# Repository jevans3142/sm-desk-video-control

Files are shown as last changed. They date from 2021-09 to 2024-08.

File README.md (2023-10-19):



# ADC Theatre - SM Desk Video Switcher

This repository hosts the hardware (in the form of KiCad schematics and PCB layouts) and 
firmware (in the form of C code) of the [ADC Theatre's](https://www.adctheatre.com) Stage 
Manager's Desk Video Switcher. This is a control panel within the SM desk on stage which 
provides remote control of a Blackmagic Design Videohub SDI switcher via Ethernet.

## Features
* Controls four screen outputs on the SM Desk, with six sources (which can differ for each of the screens) routable via 24 buttons on the desk
* Provides a special 'Show Relay' source which is switched between the Main and IR camera both on the SM Desk and around the building
* Is the interface for the Main/IR switch button the SM Desk, and also controls the mains contactor to activate the IR floodlights when in IR camera mode

## Configuration

Although some things such as number of buttons etc are fixed in hardware, some aspects can be customised via a text file 
on a microSD card read at boot. This provides the ADC with the ability to reconfigure for example which sources are availible on the SM desk without having to recompile firmware (as long as the physical buttons are relabeled of course!)

Items which can be configured: 
* Which router inputs are used as sources for each of the destinations 
* For the special 'Show Relay' source, which router inputs are the Main and IR camera 
* Which router outputs are used as 'Show Relay' outputs and should be automatically switched between Main and IR cameras in sync with the SM Desk
* IP address of the router

## Compilation
The microcontroller used is an ESP32 on an Olimex ESP32-PoE-ISO board. After standard installation of the esp-idf FreeRTOS toolchain, currently building on v5.1.1 as a stable version with the configuration included in the src folder (ie. when building do not run the idf.py set-target esp32 command as directed in the esp-idf Getting Started instructions to set up the default build config - just go straight to idf.py build)

## Hardware

There are two types of PCB required. Four 'switch-module' PCBs sit behind the four sets of buttons on the SM desk (four 
destinations with six sources each). One 'main-board' PCB is connected to these panel boards via ribbon cables, and also 
to Ethernet and power.

## Copyright
Copyright (c) 2021-2022 John Evans and contributors.
The ADC SM Desk Video Switcher hardware and firmware is released under Version 3 of the GNU General Public License.
See the LICENSE file for full details.

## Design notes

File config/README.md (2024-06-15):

# ADC Theatre - SM Desk Video Switcher
## Configuration file format

An example configuration file for the SD card is included in this folder.
Any line beginning with // is regarded as a comment. 
The variable names must not be changed otherwise they will not be recognised. The equals sign also must be present. 

### Routing panel sources/destinations
Controls which source is routed to destination for each button and which output way on the router is used for each set of buttons.
Allowed values for sources: 1-40 = sources 1-40 on router, 99 = Show relay main/IR switched 'magic source'
Allowed values for destinations: 1-40 = destinations on router

| Variable name  | Format |
| --- | --- |
| routing_panel_sources[n] | Comma seperated list of numbers |
| routing_panel_destinations[n]  | Single number  |

### Show relay sources
Controls which sources are the 'main' and 'ir' cameras for the auto-switched outputs. Allowed values: 1-40 for sources are inputs 1-40 on router

| Variable name  | Format |
| --- | --- |
| show_relay_main_source | Single number |
| show_relay_ir_source  | Single number  |

### USB enables
Controls which sources when viewed on any screen should enable the respective USB channel. Allowed values: 1-40 for sources are inputs 1-40 on router

| Variable name  | Format |
| --- | --- |
| usb_source_a | Single number |
| usb_source_b  | Single number  |

### Main/IR switched outputs
Controls which destinations are affected by the main IR button on the SM desk ie. which outputs on the router are main/IR show relay outputs.
NB: Should not include the SM desk screen outputs above - only other screens.
Allowed values: list of destionations 1-40

| Variable name  | Format |
| --- | --- |
| show_relay_switched_destination_flags | Comma seperated list of numbers |

### Router properties

| Variable name  | Format |
| --- | --- |
| router_ip | IP address in x.x.x.x format, no quotes |
| router_port  | Single number  |

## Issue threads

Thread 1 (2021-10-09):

Add output for IR relay fail warning light

jevans3142, 2021-10-09:
Add an output connector and LED drive etc for using one of the warning lights on the SM desk C&WS panel to indicate if the contactor that activates the IR floodlight power sockets is out of sync/not activating

jevans3142, 2022-09-29:
Hardware support is on PCB but needs added to software

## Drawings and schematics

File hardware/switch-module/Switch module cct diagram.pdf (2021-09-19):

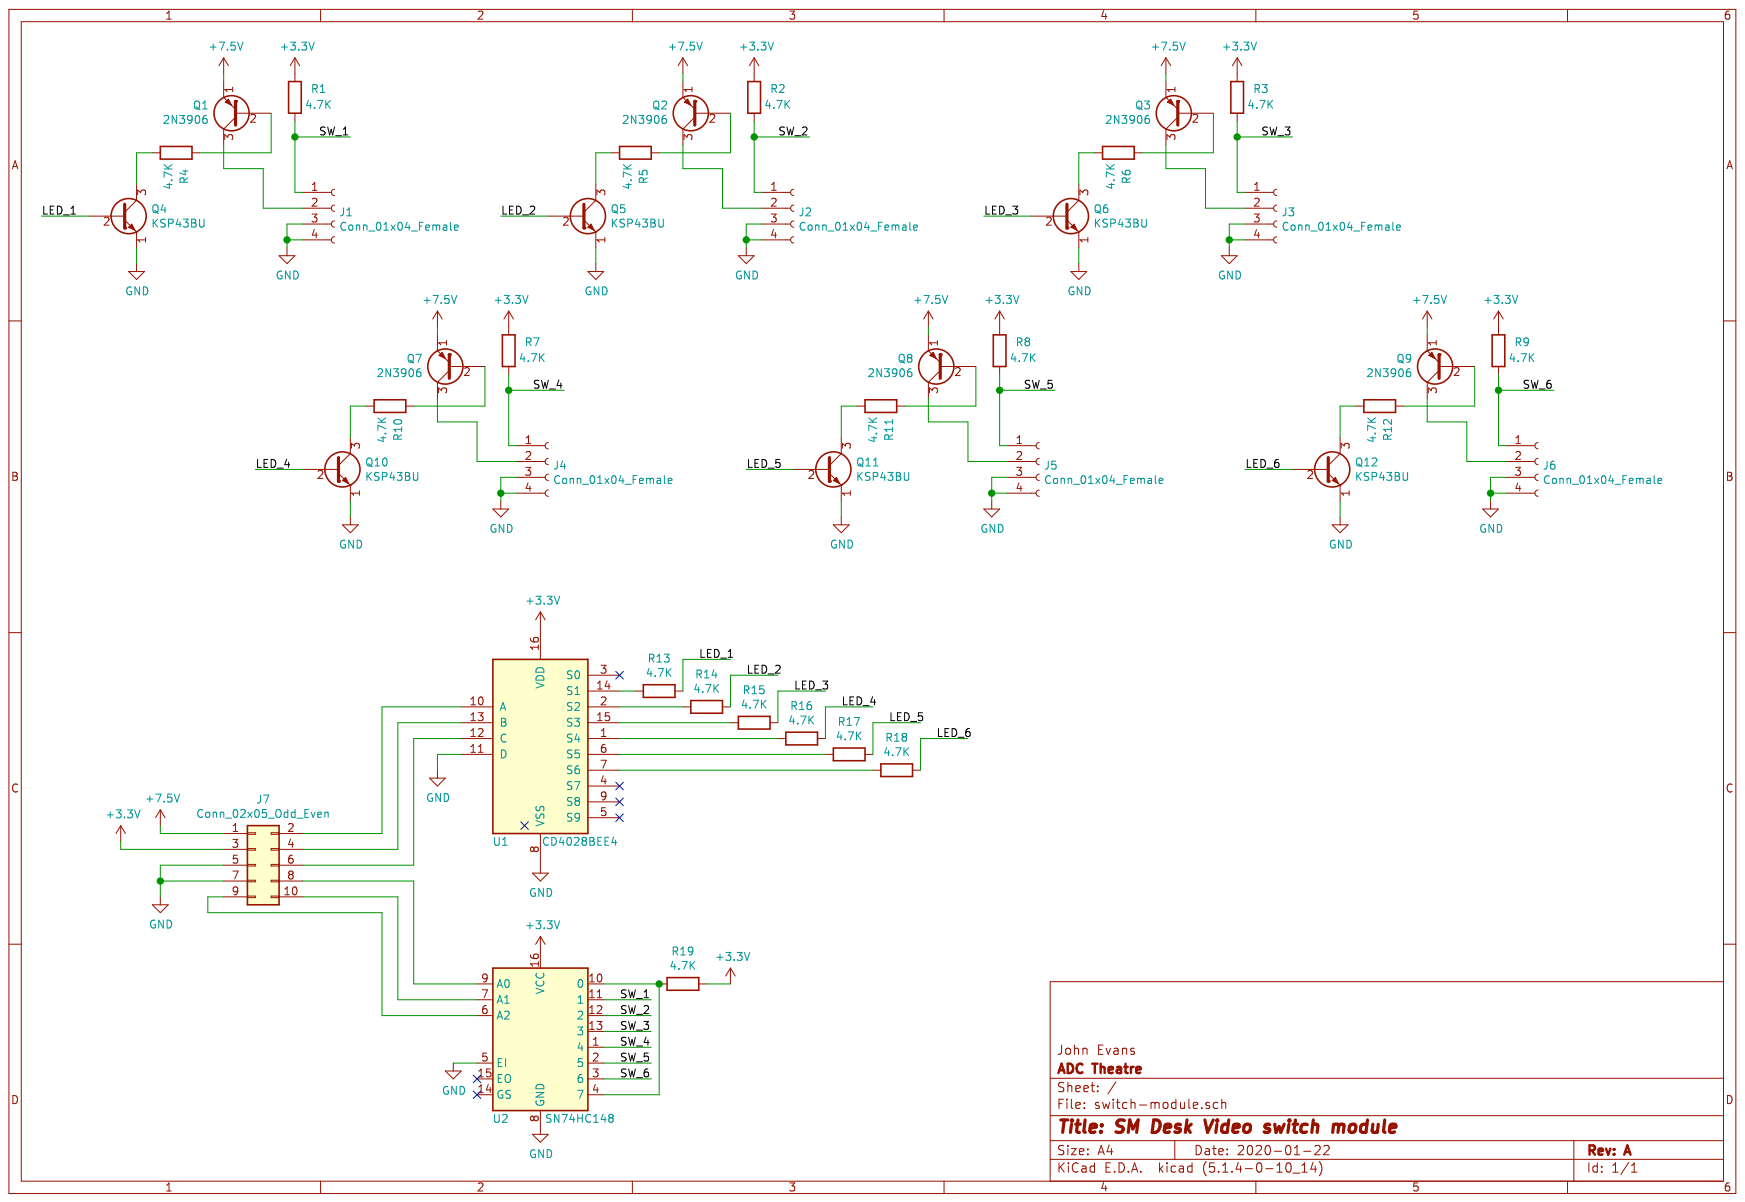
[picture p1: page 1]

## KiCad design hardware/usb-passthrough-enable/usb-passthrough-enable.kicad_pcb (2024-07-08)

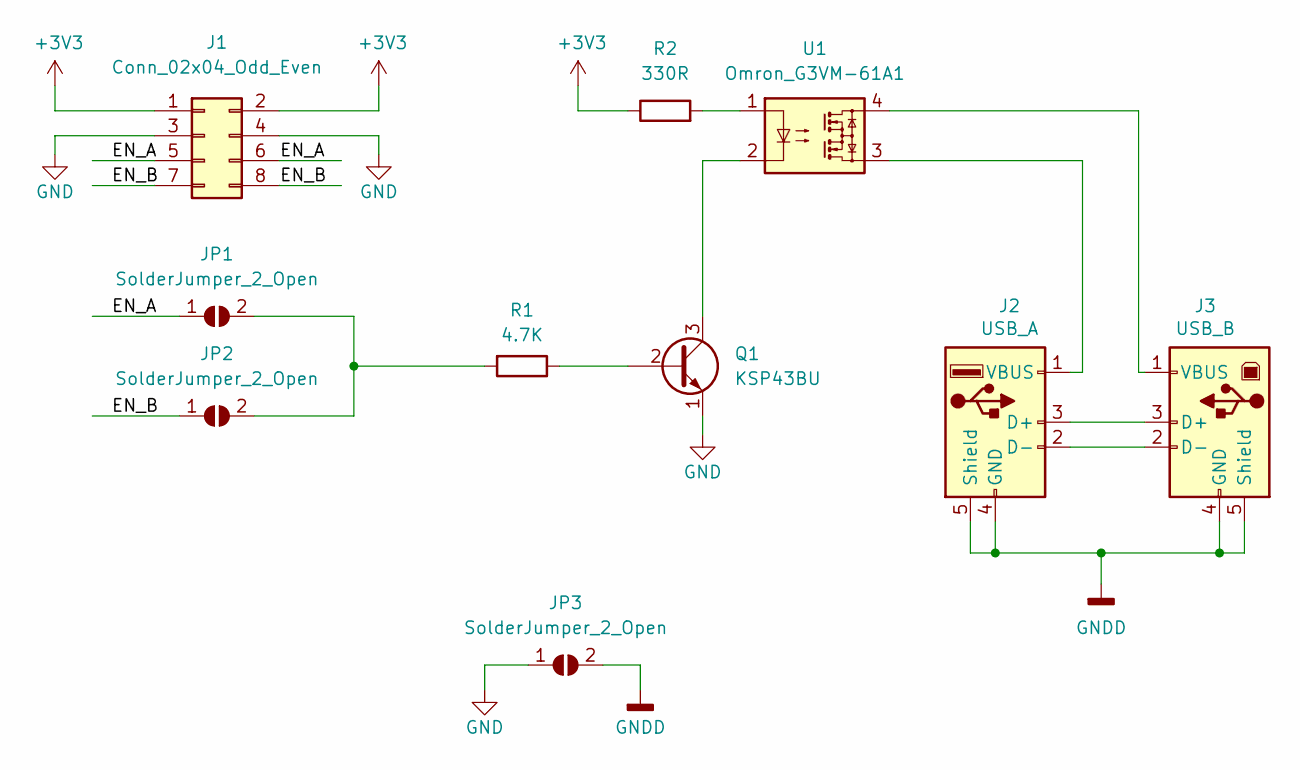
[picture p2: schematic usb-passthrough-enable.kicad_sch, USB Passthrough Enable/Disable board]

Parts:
J1: Conn_02x04_Odd_Even; PinHeader_2x04_P2.54mm_Vertical
J2: USB_A; USB_A_ASSMANN_A-USB-E-R
J3: USB_B; USB_B_ASSMANN_A-USBSB
JP1, JP2, JP3: SolderJumper_2_Open; SolderJumper-2_P1.3mm_Open_RoundedPad1.0x1.5mm
Q1: KSP43BU; TO-92_Inline
R1: 4.7K; R_Axial_DIN0207_L6.3mm_D2.5mm_P10.16mm_Horizontal
R2: 330R; R_Axial_DIN0207_L6.3mm_D2.5mm_P10.16mm_Horizontal
U1: Omron_G3VM-61A1; DIP-4_W7.62mm

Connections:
+3V3: J1.1, J1.2, R2.1
/EN_A: J1.5, J1.6, JP1.1 (A)
/EN_B: J1.7, J1.8, JP2.1 (A)
GND: J1.3, J1.4, JP3.1 (A), Q1.1 (E)
GNDD: J2.4 (GND), J2.5 (Shield), J3.4 (GND), J3.5 (Shield), JP3.2 (B)
unnamed: J2.3 (D+), J3.3 (D+)
unnamed: J2.2 (D-), J3.2 (D-)
unnamed: J2.1 (VBUS), U1.3
unnamed: J3.1 (VBUS), U1.4
unnamed: JP1.2 (B), JP2.2 (B), R1.2
unnamed: Q1.2 (B), R1.1
unnamed: Q1.3 (C), U1.2
unnamed: R2.2, U1.1

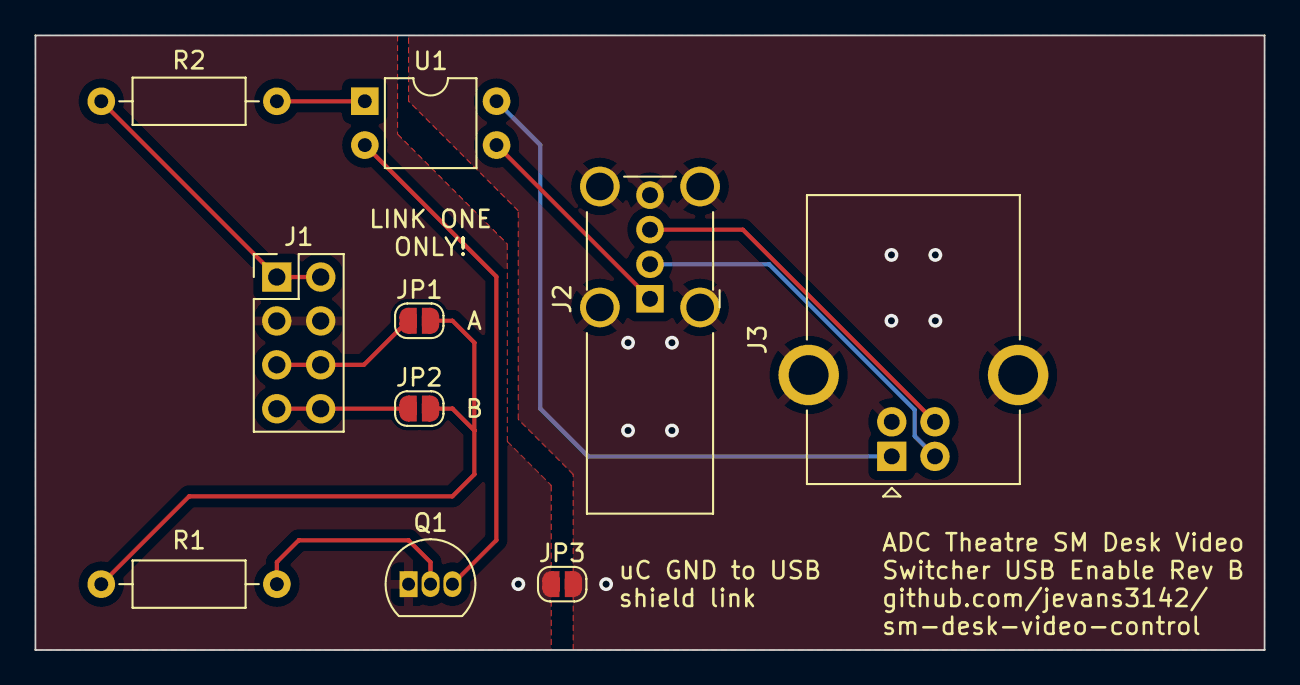
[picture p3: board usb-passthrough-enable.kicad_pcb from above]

Board: 2 copper layers, 71.1 x 35.6 mm, 10 parts (0 on the bottom side), 13 nets.

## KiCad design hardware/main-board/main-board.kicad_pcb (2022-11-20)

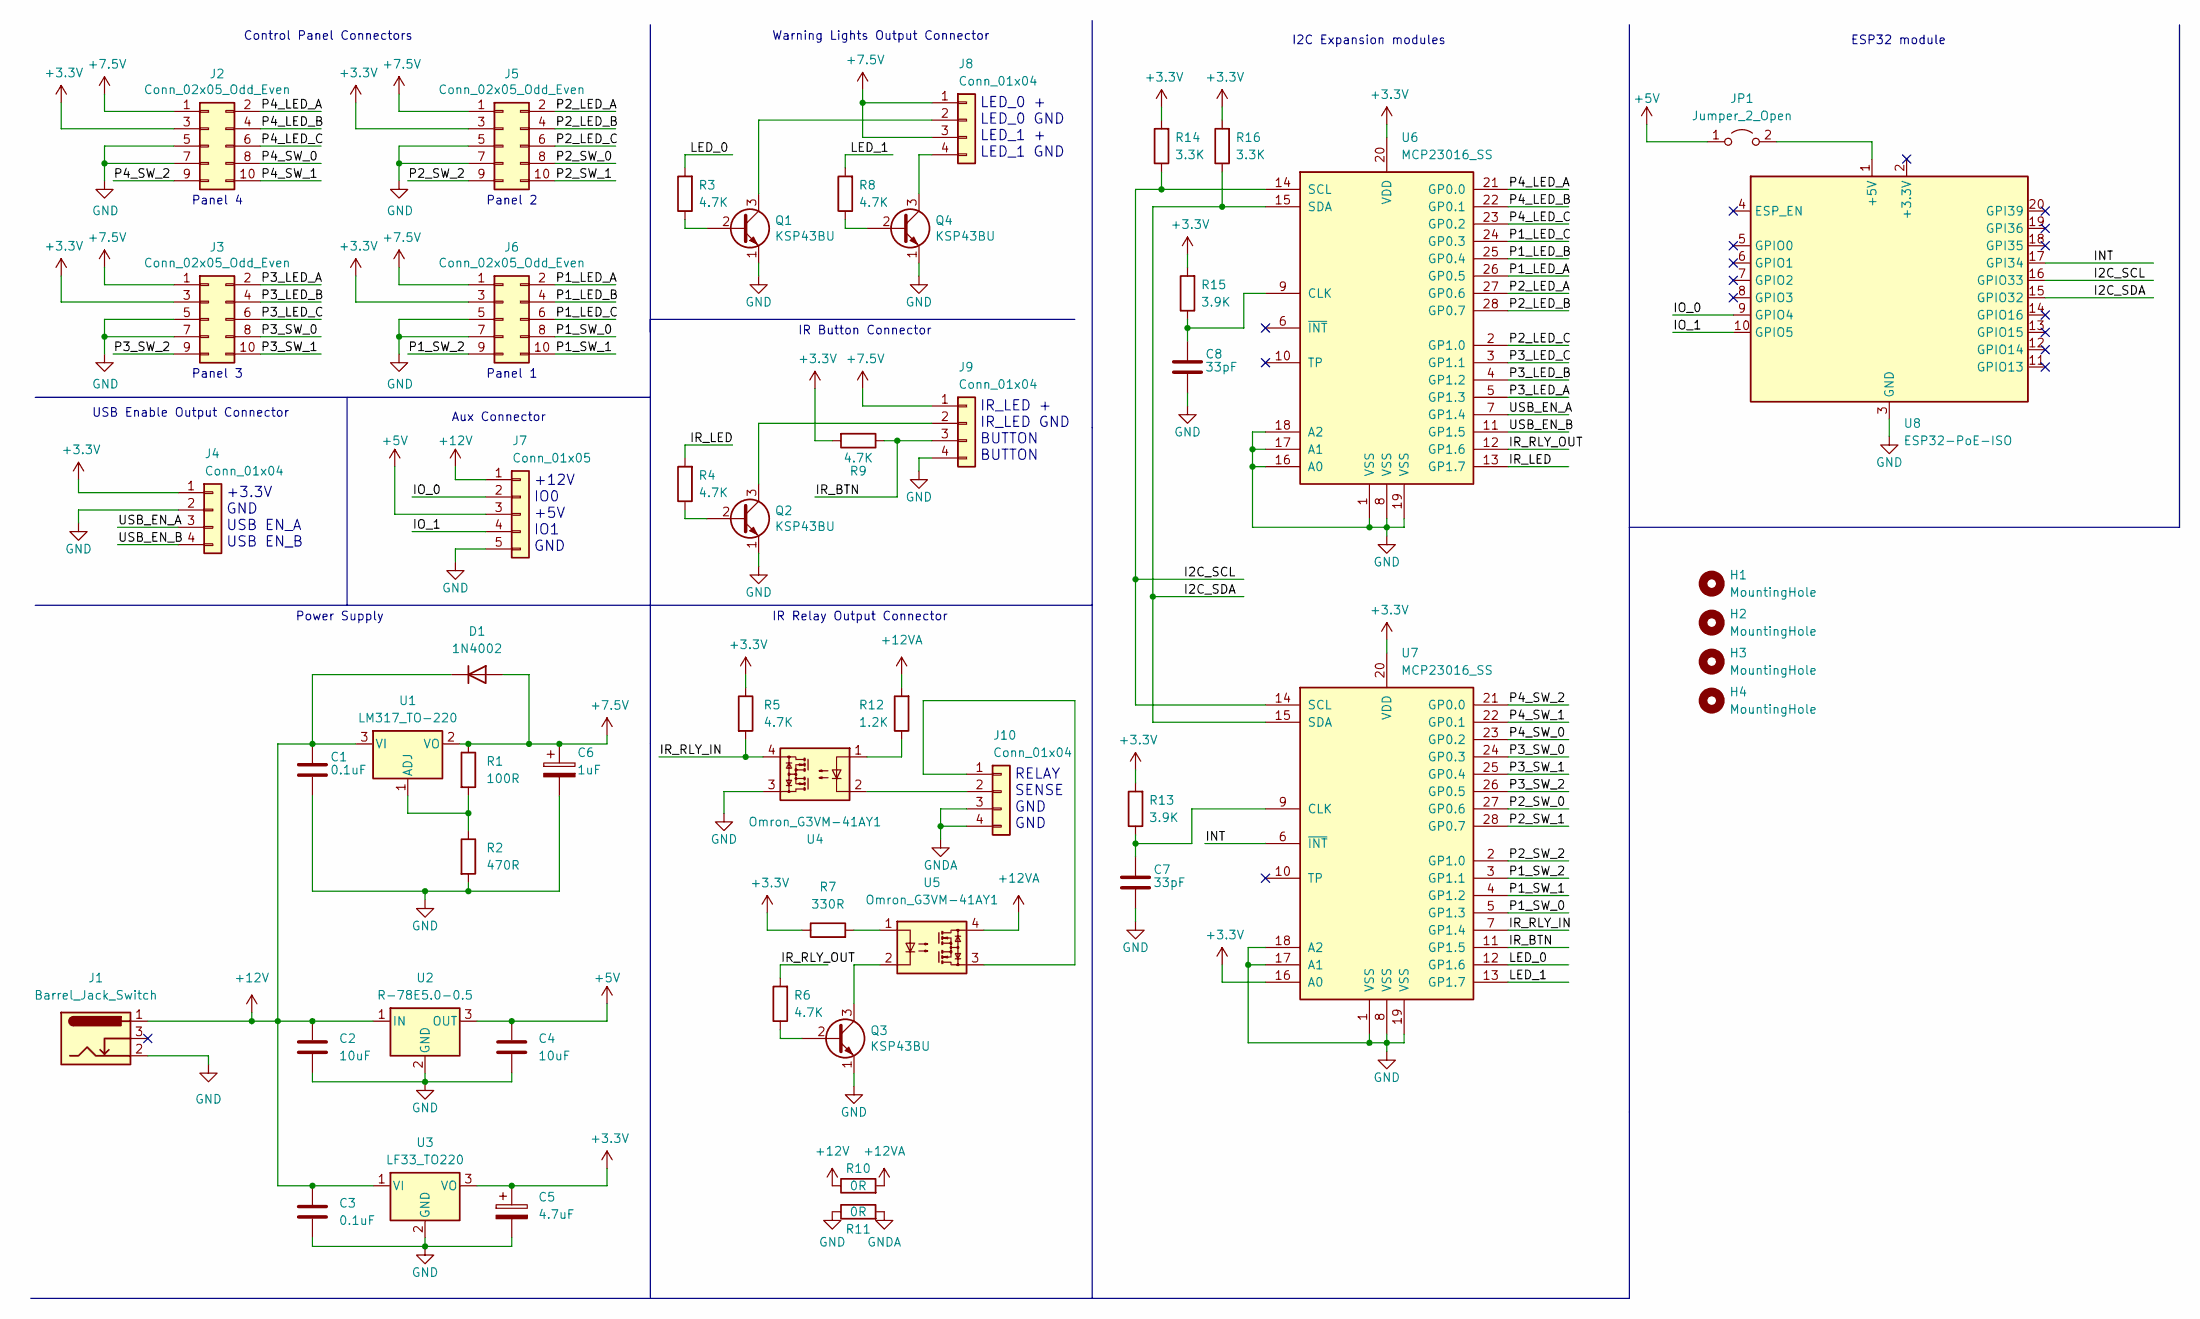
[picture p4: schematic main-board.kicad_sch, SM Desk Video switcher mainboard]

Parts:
C1, C3: 0.1uF; C_Disc_D4.7mm_W2.5mm_P5.00mm
C2, C4: 10uF; C_1210_3225Metric_Pad1.33x2.70mm_HandSolder
C5: 4.7uF; CP_Radial_D5.0mm_P2.00mm
C6: 1uF; CP_Radial_D5.0mm_P2.00mm
C7, C8: 33pF; C_Disc_D4.7mm_W2.5mm_P5.00mm
D1: 1N4002; D_DO-34_SOD68_P10.16mm_Horizontal
H1, H2, H3, H4: MountingHole; MountingHole_4.3mm_M4
J1: Barrel_Jack_Switch; BarrelJack_RS-PRO_12V1A_14.5mmL
J2, J3, J5, J6: Conn_02x05_Odd_Even; PinHeader_AWHW_2x05_P2.54mm_Vertical
J4, J8, J9, J10: Conn_01x04; PinHeader_1x04_P2.54mm_Vertical
J7: Conn_01x05; PinHeader_1x05_P2.54mm_Vertical
JP1: Jumper_2_Open; SolderJumper-2_P1.3mm_Open_TrianglePad1.0x1.5mm
Q1, Q2, Q3, Q4: KSP43BU; TO-92_Inline
R1: 100R; R_Axial_DIN0207_L6.3mm_D2.5mm_P10.16mm_Horizontal
R2: 470R; R_Axial_DIN0207_L6.3mm_D2.5mm_P10.16mm_Horizontal
R3, R4, R5, R6, R8, R9: 4.7K; R_Axial_DIN0207_L6.3mm_D2.5mm_P10.16mm_Horizontal
R7: 330R; R_Axial_DIN0207_L6.3mm_D2.5mm_P10.16mm_Horizontal
R10, R11: 0R; R_Axial_DIN0207_L6.3mm_D2.5mm_P10.16mm_Horizontal
R12: 1.2K; R_Axial_DIN0207_L6.3mm_D2.5mm_P10.16mm_Horizontal
R13, R15: 3.9K; R_Axial_DIN0207_L6.3mm_D2.5mm_P10.16mm_Horizontal
R14, R16: 3.3K; R_Axial_DIN0207_L6.3mm_D2.5mm_P10.16mm_Horizontal
U1: LM317_TO-220; TO-220-3_Horizontal_TabDown
U2: R-78E5.0-0.5; Converter_DCDC_RECOM_R-78E-0.5_THT
U3: LF33_TO220; TO-220-3_Horizontal_TabDown
U4, U5: Omron_G3VM-41AY1; DIP-4_W7.62mm
U6, U7: MCP23016_SS; DIP-28_W7.62mm
U8: ESP32-PoE-ISO; Olimex_ESP32_PoE_ISO

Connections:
+3V3: C5.1, J2.3, J3.3, J4.1, J5.3, J6.3, R5.1, R7.1, R9.2, R13.2, R14.2, R15.2, R16.2, U3.3 (VO), U6.20 (VDD), U7.16 (A0), U7.20 (VDD)
+5V: C4.1, J7.3, JP1.1 (A), U2.3 (OUT)
+7.5V: C6.1, D1.2 (A), J2.1, J3.1, J5.1, J6.1, J8.1, J8.3, J9.1, R1.1, U1.2 (VO)
+12V: C1.1, C2.1, C3.1, D1.1 (K), J1.1, J7.1, R10.1, U1.3 (VI), U2.1 (IN), U3.1 (VI)
+12VA: R10.2, R12.2, U5.4
/I2C_SCL: R14.1, U6.14 (SCL), U7.14 (SCL), U8.16 (GPIO33)
/I2C_SDA: R16.1, U6.15 (SDA), U7.15 (SDA), U8.15 (GPIO32)
/INT: U7.6 (~INT), U8.17 (GPI34)
/IO_0: J7.2, U8.9 (GPIO4)
/IO_1: J7.4, U8.10 (GPIO5)
/IR_BTN: J9.3, R9.1, U7.11 (GP1.5)
/IR_LED: R4.2, U6.13 (GP1.7)
/IR_RLY_IN: R5.2, U4.4, U7.7 (GP1.4)
/IR_RLY_OUT: R6.2, U6.12 (GP1.6)
/LED_0: R3.2, U7.12 (GP1.6)
/LED_1: R8.2, U7.13 (GP1.7)
/P1_LED_A: J6.2, U6.26 (GP0.5)
/P1_LED_B: J6.4, U6.25 (GP0.4)
/P1_LED_C: J6.6, U6.24 (GP0.3)
/P1_SW_0: J6.8, U7.5 (GP1.3)
/P1_SW_1: J6.10, U7.4 (GP1.2)
/P1_SW_2: J6.9, U7.3 (GP1.1)
/P2_LED_A: J5.2, U6.27 (GP0.6)
/P2_LED_B: J5.4, U6.28 (GP0.7)
/P2_LED_C: J5.6, U6.2 (GP1.0)
/P2_SW_0: J5.8, U7.27 (GP0.6)
/P2_SW_1: J5.10, U7.28 (GP0.7)
/P2_SW_2: J5.9, U7.2 (GP1.0)
/P3_LED_A: J3.2, U6.5 (GP1.3)
/P3_LED_B: J3.4, U6.4 (GP1.2)
/P3_LED_C: J3.6, U6.3 (GP1.1)
/P3_SW_0: J3.8, U7.24 (GP0.3)
/P3_SW_1: J3.10, U7.25 (GP0.4)
/P3_SW_2: J3.9, U7.26 (GP0.5)
/P4_LED_A: J2.2, U6.21 (GP0.0)
/P4_LED_B: J2.4, U6.22 (GP0.1)
/P4_LED_C: J2.6, U6.23 (GP0.2)
/P4_SW_0: J2.8, U7.23 (GP0.2)
/P4_SW_1: J2.10, U7.22 (GP0.1)
/P4_SW_2: J2.9, U7.21 (GP0.0)
/USB_EN_A: J4.3, U6.7 (GP1.4)
/USB_EN_B: J4.4, U6.11 (GP1.5)
GND: C1.2, C2.2, C3.2, C4.2, C5.2, C6.2, C7.2, C8.2, J1.2, J2.5, J2.7, J3.5, J3.7, J4.2, J5.5, J5.7, J6.5, J6.7, J7.5, J9.4, Q1.1 (E), Q2.1 (E), Q3.1 (E), Q4.1 (E), R2.2, R11.1, U2.2 (GND), U3.2 (GND), U4.3, U6.1 (VSS), U6.8 (VSS), U6.16 (A0), U6.17 (A1), U6.18 (A2), U6.19 (VSS), U7.1 (VSS), U7.8 (VSS), U7.17 (A1), U7.18 (A2), U7.19 (VSS), U8.3 (GND)
GNDA: J10.3, J10.4, R11.2
unnamed: C7.1, R13.1, U7.9 (CLK)
unnamed: C8.1, R15.1, U6.9 (CLK)
unnamed: J8.2, Q1.3 (C)
unnamed: J8.4, Q4.3 (C)
unnamed: J9.2, Q2.3 (C)
unnamed: J10.1, U5.3
unnamed: J10.2, U4.2
unnamed: JP1.2 (B), U8.1 (+5V)
unnamed: Q1.2 (B), R3.1
unnamed: Q2.2 (B), R4.1
unnamed: Q3.2 (B), R6.1
unnamed: Q3.3 (C), U5.2
unnamed: Q4.2 (B), R8.1
unnamed: R1.2, R2.1, U1.1 (ADJ)
unnamed: R7.2, U5.1
unnamed: R12.1, U4.1

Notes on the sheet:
+3.3V GND USB EN_A USB EN_B
IR Button Connector
Power Supply
Panel 2
Panel 4
Aux Connector
RELAY SENSE GND GND
Warning Lights Output Connector
Panel 1
USB Enable Output Connector
LED_0 + LED_0 GND LED_1 + LED_1 GND
+12V IO0 +5V IO1 GND
Panel 3
I2C Expansion modules
ESP32 module
IR_LED + IR_LED GND BUTTON BUTTON
IR Relay Output Connector
Control Panel Connectors

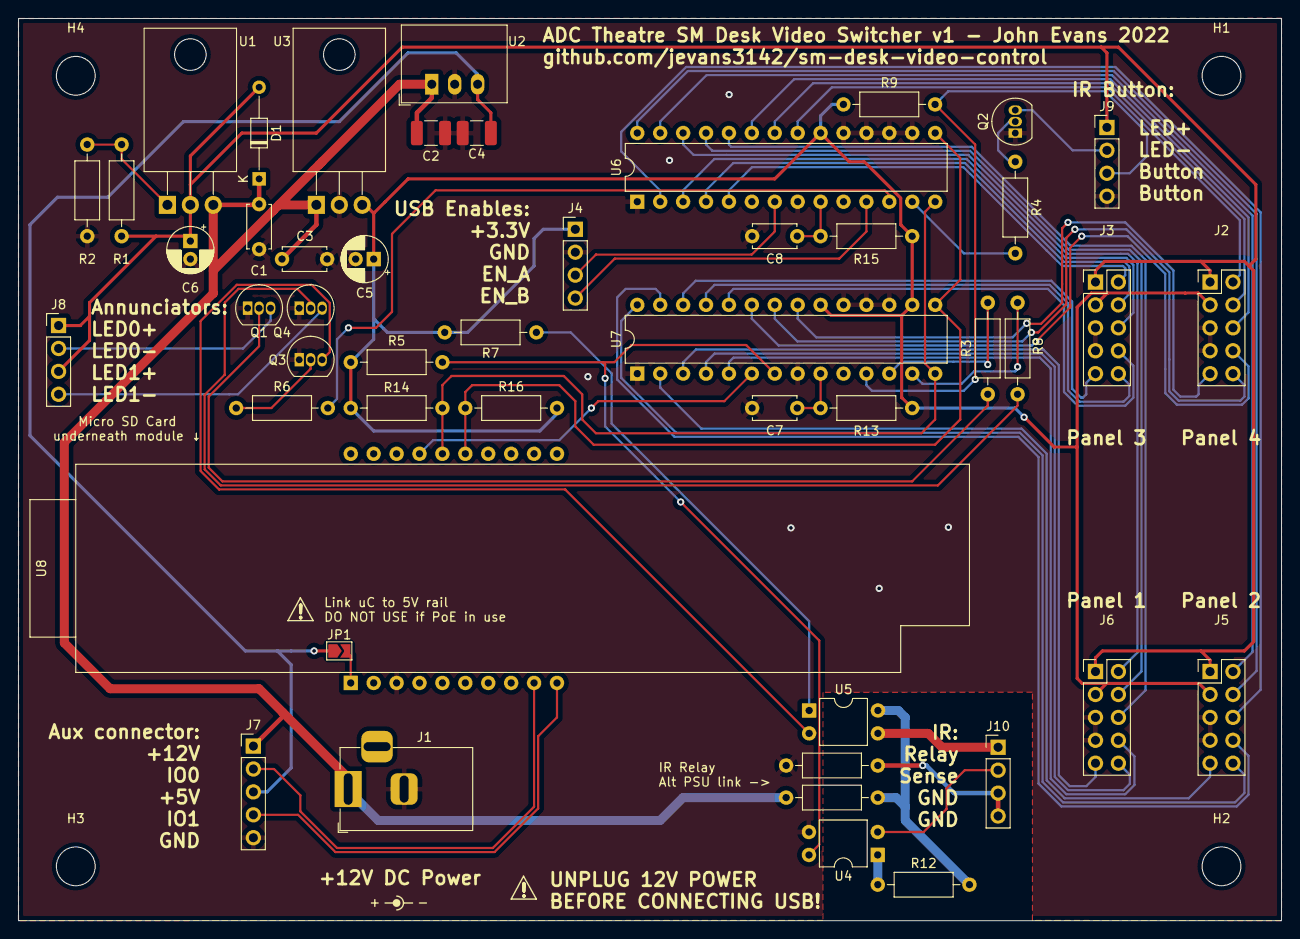
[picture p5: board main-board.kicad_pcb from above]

Board: 2 copper layers, 140.0 x 100.0 mm, 52 parts (0 on the bottom side), 60 nets.

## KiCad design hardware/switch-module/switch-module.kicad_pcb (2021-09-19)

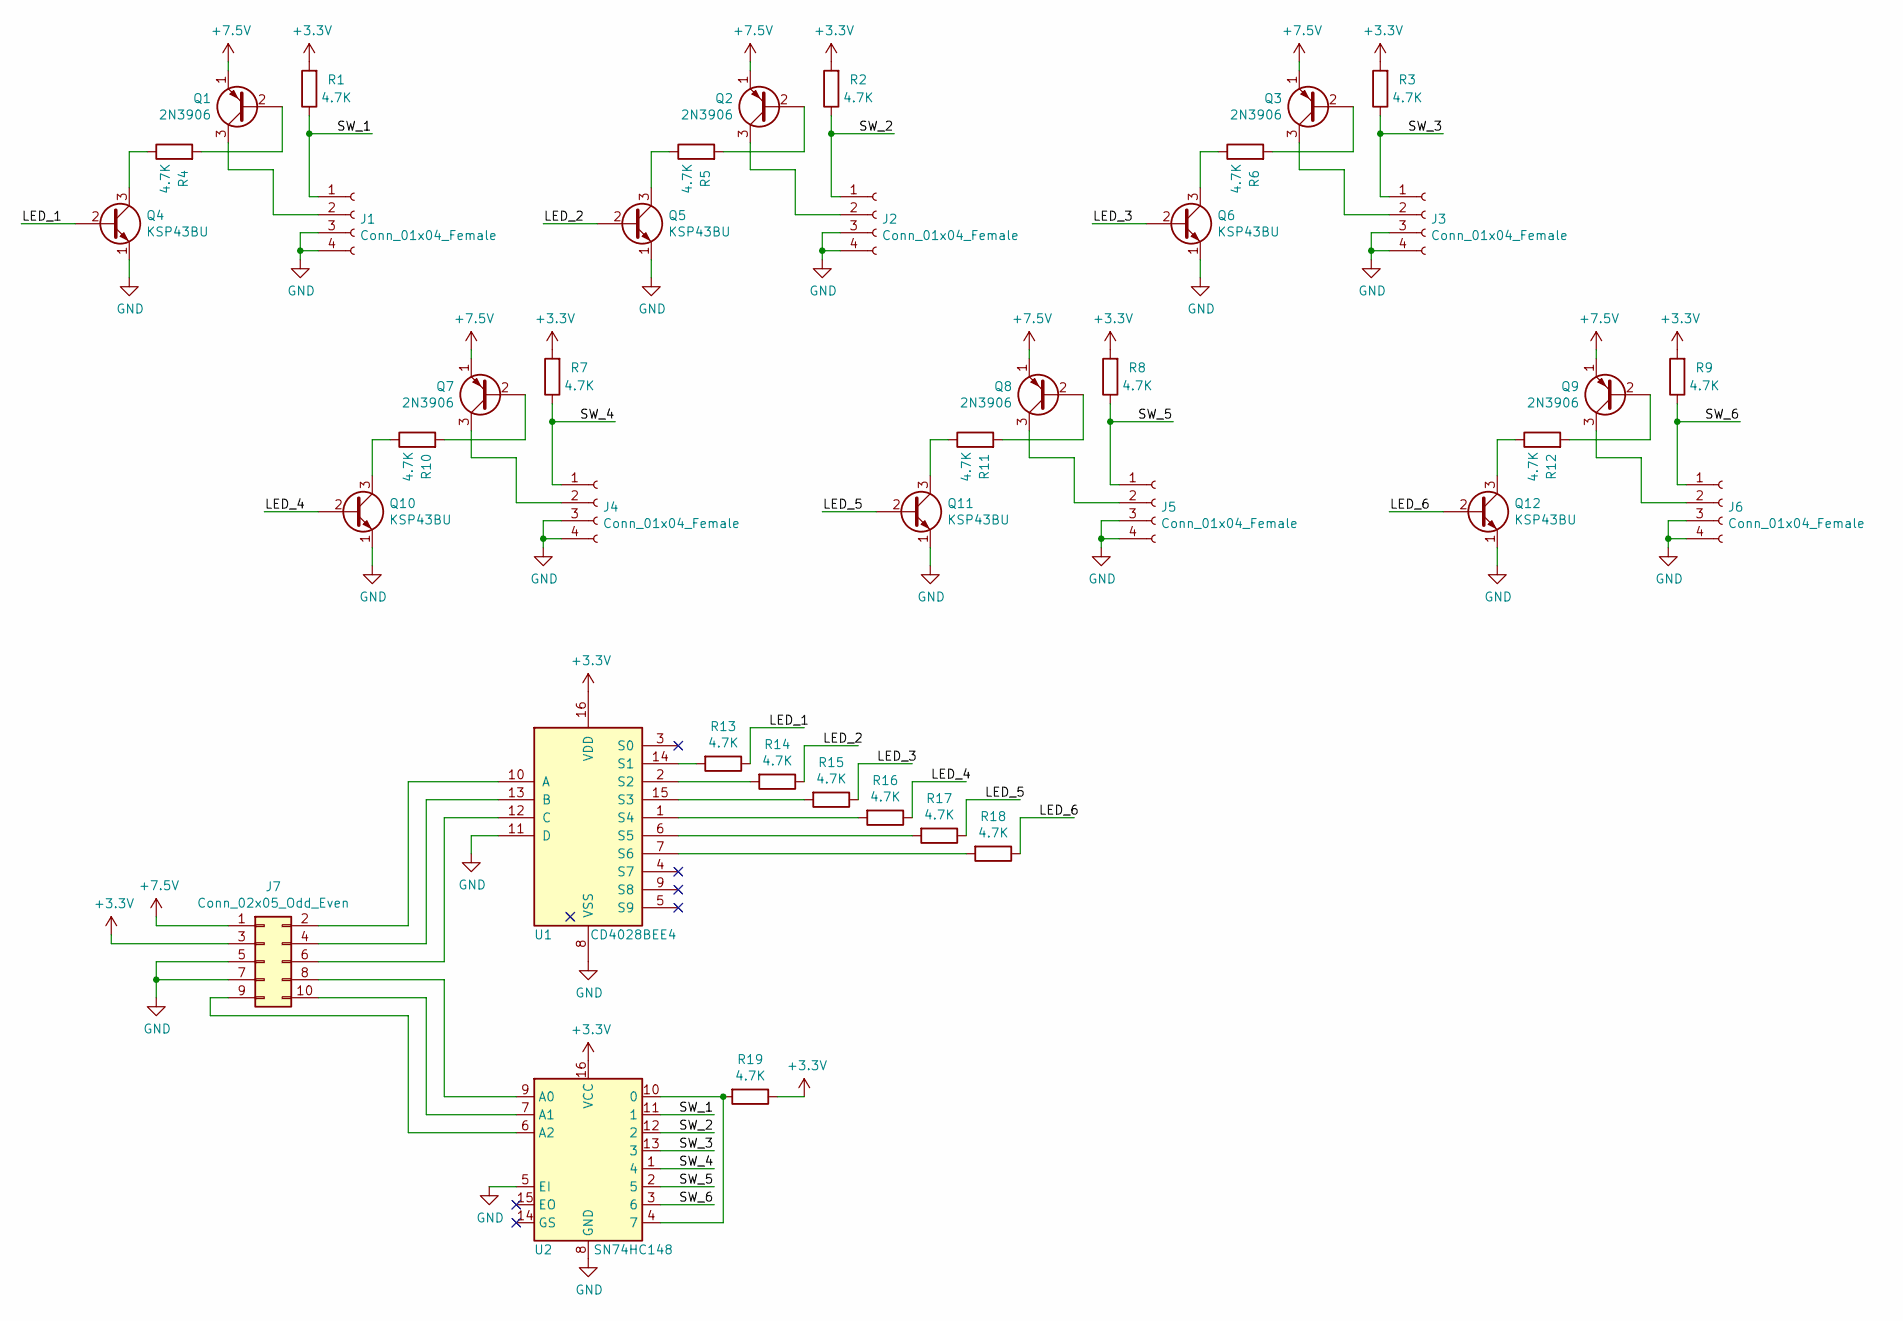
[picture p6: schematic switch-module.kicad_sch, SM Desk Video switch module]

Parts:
J1, J2, J3, J4, J5, J6: Conn_01x04_Female; PinHeader_1x04_P2.54mm_Vertical
J7: Conn_02x05_Odd_Even; PinHeader_AWHW_2x05_P2.54mm_Vertical
Q1, Q2, Q3, Q7, Q8, Q9: 2N3906; TO-92_Inline
Q4, Q5, Q6, Q10, Q11, Q12: KSP43BU; TO-92_Inline
R1, R2, R3, R4, R5, R6, R7, R8, R9, R10, R11, R12, R13, R14, R15, R16, R17, R18, R19: 4.7K; R_Axial_DIN0207_L6.3mm_D2.5mm_P10.16mm_Horizontal
U1: CD4028BEE4; DIP-16_W7.62mm_Socket
U2: SN74HC148; DIP-16_W7.62mm_Socket

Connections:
+3V3: J7.3, R1.2, R2.2, R3.2, R7.2, R8.2, R9.2, R19.1, U1.16 (VDD), U2.16 (VCC)
+7.5V: J7.1, Q1.1 (E), Q2.1 (E), Q3.1 (E), Q7.1 (E), Q8.1 (E), Q9.1 (E)
/LED_1: Q4.2 (B), R13.1
/LED_2: Q5.2 (B), R14.1
/LED_3: Q6.2 (B), R15.1
/LED_4: Q10.2 (B), R16.1
/LED_5: Q11.2 (B), R17.1
/LED_6: Q12.2 (B), R18.1
/SW_1: J1.1, R1.1, U2.11 (1)
/SW_2: J2.1, R2.1, U2.12 (2)
/SW_3: J3.1, R3.1, U2.13 (3)
/SW_4: J4.1, R7.1, U2.1 (4)
/SW_5: J5.1, R8.1, U2.2 (5)
/SW_6: J6.1, R9.1, U2.3 (6)
GND: J1.3, J1.4, J2.3, J2.4, J3.3, J3.4, J4.3, J4.4, J5.3, J5.4, J6.3, J6.4, J7.5, J7.7, Q4.1 (E), Q5.1 (E), Q6.1 (E), Q10.1 (E), Q11.1 (E), Q12.1 (E), U1.8 (VSS), U1.11 (D), U2.5 (EI), U2.8 (GND)
unnamed: J1.2, Q1.3 (C)
unnamed: J2.2, Q2.3 (C)
unnamed: J3.2, Q3.3 (C)
unnamed: J4.2, Q7.3 (C)
unnamed: J5.2, Q8.3 (C)
unnamed: J6.2, Q9.3 (C)
unnamed: J7.2, U1.10 (A)
unnamed: J7.4, U1.13 (B)
unnamed: J7.6, U1.12 (C)
unnamed: J7.8, U2.9 (A0)
unnamed: J7.9, U2.6 (A2)
unnamed: J7.10, U2.7 (A1)
unnamed: Q1.2 (B), R4.2
unnamed: Q2.2 (B), R5.2
unnamed: Q3.2 (B), R6.2
unnamed: Q4.3 (C), R4.1
unnamed: Q5.3 (C), R5.1
unnamed: Q6.3 (C), R6.1
unnamed: Q7.2 (B), R10.2
unnamed: Q8.2 (B), R11.2
unnamed: Q9.2 (B), R12.2
unnamed: Q10.3 (C), R10.1
unnamed: Q11.3 (C), R11.1
unnamed: Q12.3 (C), R12.1
unnamed: R13.2, U1.14 (S1)
unnamed: R14.2, U1.2 (S2)
unnamed: R15.2, U1.15 (S3)
unnamed: R16.2, U1.1 (S4)
unnamed: R17.2, U1.6 (S5)
unnamed: R18.2, U1.7 (S6)
unnamed: R19.2, U2.4 (7), U2.10 (0)

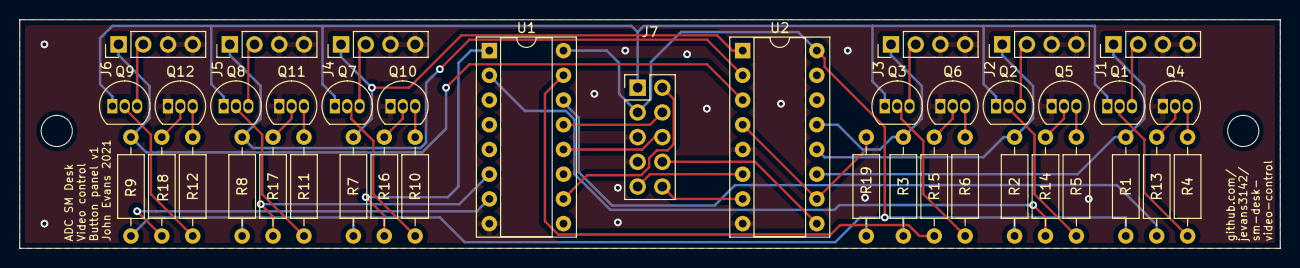
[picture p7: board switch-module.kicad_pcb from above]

Board: 2 copper layers, 129.5 x 23.5 mm, 40 parts (0 on the bottom side), 46 nets.

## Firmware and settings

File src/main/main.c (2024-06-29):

#include <stdio.h>
#include <string.h>
#include <stdlib.h>
#include "freertos/FreeRTOS.h"
#include "freertos/semphr.h"
#include "freertos/task.h"
#include "esp_err.h"
#include "esp_log.h"
#include "esp_system.h"
#include "nvs_flash.h"
#include "freertos/queue.h" 

#include "main.h"
#include "local_io.h"
#include "ethernet.h"
#include "storage.h"

// Queue handles input to logic from button panels, messages received on ethernet, relay state changes
// Avoids having to poll inputs from main logic (polling, denbouncing, buffering of buttons etc handled in local_io module)
QueueHandle_t input_event_queue; 

// Holds the various settings
// Note that route info is held in 'physical' 1-40 numbering not the 0-39 form - decrements are applied below when commands are sent
struct Settings_Struct settings;

// Current main/IR state for show relay
// Held here rather than on switcher, because of the complexity of the multiple outputs switched and the possiblity they get out of sync
u_int8_t relay_ir_state = RELAY_STATE_MAIN;
// This holds a 'cache' state of if a button panel is currently viewing show relay and therefore if we need to do a main/IR switch for it
u_int8_t cache_panel_relay_states[4];

// USB enable state
// Cache of actual routing for each panel, used only for USB enables not LEDs
u_int8_t cache_panel_routing[4];
// Cache of state
u_int8_t usb_enable_a_state;
u_int8_t usb_enable_b_state;

static const char *TAG = "main";

static void input_logic_task(void)
{
    // Task which responds to button presses on the front panel, ethernet messages, and relay state changes
    // Uses a queue to respond when required

    for (uint8_t panel = 0; panel<4; panel++)
    {   
        cache_panel_relay_states[panel] = 0;
        cache_panel_routing[panel] = 0;
    }
    usb_enable_a_state = 0;
    usb_enable_b_state = 0;

    set_ir_relay_state(RELAY_STATE_MAIN);

    set_usb_enable_a(usb_enable_a_state);
    set_usb_enable_b(usb_enable_b_state);

    while(1)
    {   
        struct Queued_Input_Message_Struct incoming_msg;
        if (xQueueReceive(input_event_queue, &incoming_msg, (TickType_t) portMAX_DELAY) == pdTRUE)
        {
            // Message recieved from queue
            ESP_LOGI(TAG,"Processing message in input logic, type:%i",incoming_msg.type);

            switch (incoming_msg.type)
            {
            case IN_MSG_TYP_ROUTING:
                // Routing input from button panel - send command to switcher
                ESP_LOGI(TAG,"Sending video routing message");
                uint8_t input = settings.routing_panel_sources[incoming_msg.panel][incoming_msg.panel_button];
                uint8_t output = settings.routing_panel_destinations[incoming_msg.panel];

                if (input == 99 )
                {
                    // Special case to handle main/IR show relay
                    if (relay_ir_state == RELAY_STATE_MAIN)
                    {
                        input = settings.show_relay_main_source;
                    } else {
                        input = settings.show_relay_ir_source;
                    }
                    cache_panel_relay_states[incoming_msg.panel] = 1;
                } else {
                    cache_panel_relay_states[incoming_msg.panel] = 0;
                }

                // Decrement in/outs by 1 to go from physical 1-40 numbering to zero index 
                send_video_route(input - 1, output - 1);

                break;
            case IN_MSG_TYP_IR_TOGGLE:
                // IR Button - send command macro to switcher 
                ESP_LOGI(TAG,"Toggling IR");

                

                uint8_t new_source = 0; 
                if (relay_ir_state == RELAY_STATE_MAIN)
                {
                    // Switch to IR 
                    relay_ir_state = RELAY_STATE_IR;
                    new_source = settings.show_relay_ir_source;
                    set_ir_button_led(RELAY_STATE_IR);  
                    set_ir_relay_state(RELAY_STATE_IR);
                } else {
                    // Switch to Main
                    relay_ir_state = RELAY_STATE_MAIN;
                    new_source = settings.show_relay_main_source;  
                    set_ir_button_led(RELAY_STATE_MAIN);  
                    set_ir_relay_state(RELAY_STATE_MAIN);
                }

                // First identify if we are currently viewing show relay and need to switch 
                for (uint8_t panel = 0; panel<4; panel++)
                {   
                    if( cache_panel_relay_states[panel] == 1)
                    {
                        // Then we are currently watching show relay and need to switch
                        if (relay_ir_state == RELAY_STATE_MAIN)
                        {
                            // Decrement in/outs by 1 to go from physical 1-40 numbering to zero index 
                            send_video_route(settings.show_relay_main_source - 1, settings.routing_panel_destinations[panel] - 1);
                        } else {
                            // Decrement in/outs by 1 to go from physical 1-40 numbering to zero index 
                            send_video_route(settings.show_relay_ir_source - 1, settings.routing_panel_destinations[panel] - 1);
                        }
                    }
                }

                // Also loop through all secondary channels that get main/IR switched
                for (uint8_t dest = 0; dest<40; dest++)
                {
                    if (settings.show_relay_switched_destination_flags[dest] != 0)
                    {
                        // Decrement input by 1 to go from physical 1-40 numbering to zero index 
                        send_video_route(new_source - 1, dest);
                        vTaskDelay(RELAY_CHANGEOVER_RIPPLE_INTERVAL); 
                    }
                }

                break;
            case IN_MSG_TYP_RELAY_STATE:
                // IR Flood relay - process state change

                // TODO

                break;
            case IN_MSG_TYP_ETHERNET:
                // Incoming text message on ethenet
                ESP_LOGI(TAG,"Processing routing confirm message");
                // Work out if the incoming routing confirm applies to any of our screens
                u_int8_t found_panel = 255; // Hacky hack hack - use 255 as a 'not found' flag
                u_int8_t found_button = 0; 
                // Increment in/outs by 1 to go from zero index to physical 1-40 numbering 
                for (uint8_t panel = 0; panel<4; panel++)
                {
                    if ((incoming_msg.output + 1) == settings.routing_panel_destinations[panel])
                    {
                        // So it is one of our screens
                        found_panel = panel;
                        for (uint8_t button = 0; button<6; button++)
                        {
                            if ((incoming_msg.input + 1) == settings.routing_panel_sources[panel][button])
                            {
                                // and it's one of our outputs 
                                found_button = button + 1; // Got to convert back from zero index to physical button, because 0 = no LED lit
                                cache_panel_relay_states[panel] = 0;
                                cache_panel_routing[panel] = incoming_msg.input + 1;
                                break;
                            } 
                            if ( (settings.routing_panel_sources[panel][button] == 99) && (((incoming_msg.input + 1) == settings.show_relay_main_source) || ((incoming_msg.input + 1) == settings.show_relay_ir_source)) )
                            {
                                // It's one of the show relay sources
                                found_button = button + 1; // Got to convert back from zero index to physical button, because 0 = no LED lit
                                cache_panel_relay_states[panel] = 1;
                                cache_panel_routing[panel] = incoming_msg.input + 1;
                                break;
                            }
                        }
                        break;
                    }
                }

                if (found_panel != 255)
                {
                    // This means we have a confirmed routing change to one of our screens
                    set_button_led_state(found_panel,found_button);
                    ESP_LOGI(TAG, "Cache of routing state: %i,%i,%i,%i", cache_panel_routing[0], cache_panel_routing[1], cache_panel_routing[2], cache_panel_routing[3]);
                    
                    // Now work out what USB enable state should be 
                    uint8_t new_a_state = 0; 
                    uint8_t new_b_state = 0;
                    for (uint8_t panel = 0; panel<4; panel++)
                    {   
                        if (cache_panel_routing[panel] == settings.usb_source_a)
                        {
                            new_a_state = 1;
                        }
                        if (cache_panel_routing[panel] == settings.usb_source_b)
                        {
                            new_b_state = 1;
                        }
                    }
                    if (new_a_state != usb_enable_a_state)
                    {
                        usb_enable_a_state = new_a_state;
                        set_usb_enable_a(usb_enable_a_state);
                        ESP_LOGI(TAG, "USB A enable set to %d",usb_enable_a_state);
                    }
                    if (new_b_state != usb_enable_b_state)
                    {
                        usb_enable_b_state = new_b_state;
                        set_usb_enable_b(usb_enable_b_state);
                        ESP_LOGI(TAG, "USB B enable set to %d",usb_enable_b_state);
                    }

                }

                break;
            default:
                ESP_LOGW(TAG,"Input message unknown:%i",incoming_msg.type);
                break;
            }
            
        }
    }

}

static void local_test_mode(void)
{
    // Vegas mode - LED and button test only
    while (1)
    {
        // Do some dumb polling of the buttons to light any up that are selected
        for (uint8_t panel = 0; panel<4; panel++)
        {
                set_button_led_state(panel,get_button_panel_state(panel));
                set_ir_button_led(get_ir_button_state());
                vTaskDelay(5);
        }
    }
        
}

void app_main(void)
{   
    // Set up input event queue
    input_event_queue = xQueueCreate (32, sizeof(struct Queued_Input_Message_Struct)); 
    if (input_event_queue == NULL)
    {
        ESP_LOGE(TAG,"Unable to create input event queue, rebooting");
        esp_restart();
    }

    // Retrive settings from SD card 
    settings = get_settings();

    // Set up ethernet stack and communication with video router
    setup_ethernet(settings.router_ip, settings.router_port, &input_event_queue);
    setup_local_io(&input_event_queue);  

    vTaskDelay(100); // Wait to see if buttons are being held down
    //Check to see if we're heading into 'vegas mode' for testing rather than the proper application
    if ((get_button_panel_state(0) == 1) && (get_button_panel_state(2) == 1))
    {
        ESP_LOGW(TAG,"Going into local test mode");
        local_test_mode();
        return; 
    } 

    xTaskCreate( (TaskFunction_t) input_logic_task, "input_logic_task", 2048, NULL, 5, NULL);
}

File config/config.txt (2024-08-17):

// SM Desk Video switcher config file
// All lines starting // are regarded as comments and are ignored
// Variable names and file format must NOT be changed
// Where multiple numbers are allowed, separate with commas

// Routing panel sources/destinations
// Controls which source is routed to destination for each button
// Also controls which output way on the router is used for each set of buttons
// Allowed values for sources: 1-40 = for sources 1-40 on router, 99 = Show relay main/IR switched
// Allowed values for destinations: 1-40 = destinations on router
// ==================

// Button panel 1 (main screen left)
routing_panel_sources[0] = 99,6,5,4,2,3
routing_panel_destinations[0] = 1

// Button panel 2 (main screen right)
routing_panel_sources[1] = 99,6,5,4,2,3
routing_panel_destinations[1] = 2

// Button panel 3 (aux screen left)
routing_panel_sources[2] = 99,6,5,4,2,3
routing_panel_destinations[2] = 3

// Button panel 4 (aux screen right)
routing_panel_sources[3] = 99,6,5,4,2,3
routing_panel_destinations[3] = 4


// Show relay sources
// Controls which sources are the 'main' and 'ir' cameras for the auto-switched outputs
// Allowed values: 1-40 for sources 1-40 on router
// ===================
show_relay_main_source = 8
show_relay_ir_source = 7 

// USB enables
// Controls which sources when viewed on any screen should enable the respective USB channel.
// Allowed values: 1-40 for sources 1-40 on router
// ===================
usb_source_a = 2
usb_source_b = 3 


// Main/IR switched outputs
// Controls which destinations are affected by the main IR button on the SM des
// ie. main/IR show relay outputs on the router
// NB: Should not include the SM desk screen outputs above - only other screens
// Allowed values: list of destionations 1-40
// ==================
show_relay_switched_destination_flags = 13,14,25,26,27,28,29,30,31,32


// Router properties
// IPv4 Address and port
router_ip = 192.168.11.41
router_port = 9990

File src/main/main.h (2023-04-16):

// SM Desk video controller

#ifndef MAIN_H_INCLUDED
#define MAIN_H_INCLUDED

// Used for commands in queue to input logic
struct Queued_Input_Message_Struct {
    uint8_t type; // See below defines

    uint8_t panel; // Used for a routing command (which panel)
    uint8_t panel_button; // Used for a routing command (which button within the panel)

    uint8_t input; // Used for an incoming routing confirm
    uint8_t output; // Used for an incoming routing confirm 
};

// Definitions of message type for input messages 
#define IN_MSG_TYP_ROUTING 0
#define IN_MSG_TYP_IR_TOGGLE 1
#define IN_MSG_TYP_RELAY_STATE 2
#define IN_MSG_TYP_ETHERNET 3


// Definitions of Main/IR state for show relay
#define RELAY_STATE_MAIN 0
#define RELAY_STATE_IR 1

// How long to leave between each IR changeover in ticks
#define RELAY_CHANGEOVER_RIPPLE_INTERVAL 3

#endif

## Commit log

2021-09-19 Add switch module PCB design
    v1 design for PCB that sits behind a module of 6 buttons and encodes/decodes into 3 bit format to connect to microcontroller. Also provides transistors for driving LEDs at a higher voltage than logic.
    [switch-module-B_Cu.gbr, switch-module-B_Mask.gbr, switch-module-B_Paste.gbr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]
2021-10-17 Interface to button panels
    Add basic interface to button panels and LEDs; debouncing to be added later
2021-10-24 Correct buttons code
    After hardware testing switch panel, correct logic errors in buttons read code
2021-10-24 Basic connection to switcher
    Add structure to main loop to maintain a connection to the videohub over Ethernet
2021-10-25 Add functions for IR button and warning lights
    Basic functions for IR button, IR relay and ethernet fail warning lights
2021-10-25 Add DHCP lease renew
    Command in main loop to tell arduino to keep our lease live
2022-01-16 Updates to PCB layouts
    [main-board.kicad_pcb, main-board.sch]
2022-01-29 Update README with new Teensyduino version
2022-02-03 Change control panel pins
    to avoid inbuilt devboard LED
2022-05-30 Update main-board PCB
    Update main board PCB to Kicad 6.0 as well as roughly complete PCB layout
    [main-board.kicad_pcb, main-board.kicad_sch, main-board.sch]
2022-06-03 Complete main board schematic
    [main-board.kicad_sch]
2022-09-19 Switch microcontroller to ESP32
    Using Olimex ESP32-PoE-ISO board - initial software commit, PCB still to modify
2022-10-10 Basic I2C funcs
    Read/write to external modules
2022-10-15 PCB updates
    Alter schematic to use ESP32 and add final PCB for USB enable/disables
    [main-board.kicad_pcb, main-board.kicad_sch, switch-module.kicad_sch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]
2022-11-20 Rev A mainboard PCB
    Altered to split IR relay off into isolated section
    [main-board.kicad_pcb, main-board.kicad_sch]
2022-12-25 Complete basic local IO code
    Rough draft of I2C interfacing and so on; some funcs incomplete in particular response to board power on/off - some level of debouncing and using interrupts rather than polling still todo.
2023-03-26 Add settings load from SD card
    Add module which loads and parses config file from SD card, description of config file format
    [config.txt]
2023-03-26 Basic ethernet module, command send logic
    Add socket based ethernet logic that will handle sending of commands from the input logic. Should robustly(ish?) handle being unplugged/replugged etc from ethernet cable, router being power cycled et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
2023-04-02 Add processing of incoming video routing confirm messages
    Add basic TCP text message receive loop and add to main logic to switch button LEDs when required. Corrected some off by one errors.
    [ethernet.c, local_io.c, main.c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]
2023-04-15 Set correct MAC and default router IP
    [ethernet.c]
2023-04-15 Ignore KiCad backup files in gitgnore
2023-04-16 Add vegas mode
    Hold down leftmost two source buttons on SM desk panel during boot to enter a test mode for buttons and LEDs
2023-04-16 IR logic/coping with SM Desk reset
    All logic for switching IR and coping with PSU up/down
    [ethernet.c, local_io.c, local_io.h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]
2023-04-17 Update sample config file
    To be in line with current setup
    [config.txt]
2023-05-02 Fix vegas mode
    Was broken by fix for SM desk PSU restart, was trying to trigger ethernet commands that weren't there
    [local_io.c, local_io.h, main.c]
2023-05-02 Properly fix vegas mode
    Honestly, this time...
    [local_io.c, local_io.h, main.c]
2023-06-04 Like, really, really fix vegas mode
    Tested at ADC unit and needed extra delay to work...
    [main.c]
2023-06-04 Fix ethernet/TCP timeout bug
    Add timeouts to reset connection
    [ethernet.c]
2023-10-15 Update to ESP v5.1.1
    Includes fix for mistake in code exposed by GCC upgrade - static variables weren't correctly marked
    [ethernet.c, local_io.c]
2024-06-15 Fix not powering on Ethernet PHY
    Wasn't properly changed as part of ESP 5.1.1 update
    [ethernet.c]
2024-06-15 USB switching
    Add initial support for USB switching depending on screen viewed
    [config.txt]
2024-06-29 Add logging for USB switching, update default file
    [config.txt]
2024-06-29 Fix partial block issue with TCP stack
    [ethernet.c]
2024-07-08 Rev B USB switching PCB
    Correct error in ground plane
    [usb-passthrough-enable.kicad_pcb, usb-passthrough-enable.kicad_sch]
2024-08-17 Update Main/IR config to current ADC setup in config file
    [config.txt]
